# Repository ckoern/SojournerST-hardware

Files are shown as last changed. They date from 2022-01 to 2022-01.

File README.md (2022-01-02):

# SojournerST-hardware
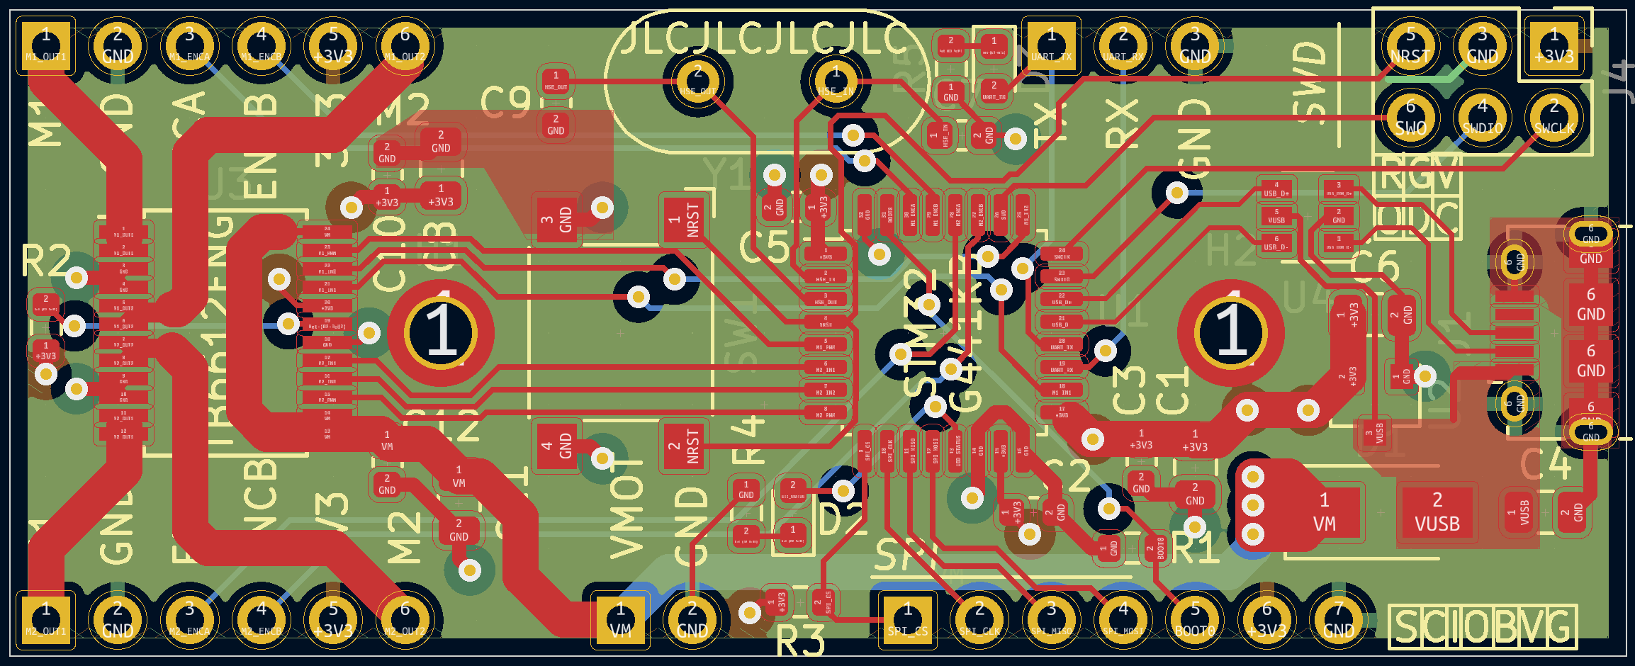
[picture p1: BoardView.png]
Board Top View

KiCad project for the SojournerST two-channel closed-loop Motor Driver Board.
The firmware project can be found [here](https://github.com/ckoern/SojournerST).

The board is based on the TB6612 motor driver IC controlled via an STM32G441 (F4 should work as well) microcontroller and is designed to fit into a breadboard but also provides mounting holes to integrate it into a custom platform.

The controller uses quadrature encoder input to provide closed-loop PWM control to the driver IC. Power can either be supplied via USB to supply both logic and driver voltage or via a 3V3 logic and a motor voltage input (max. 15V).

Commanding can be done via UART or SPI.

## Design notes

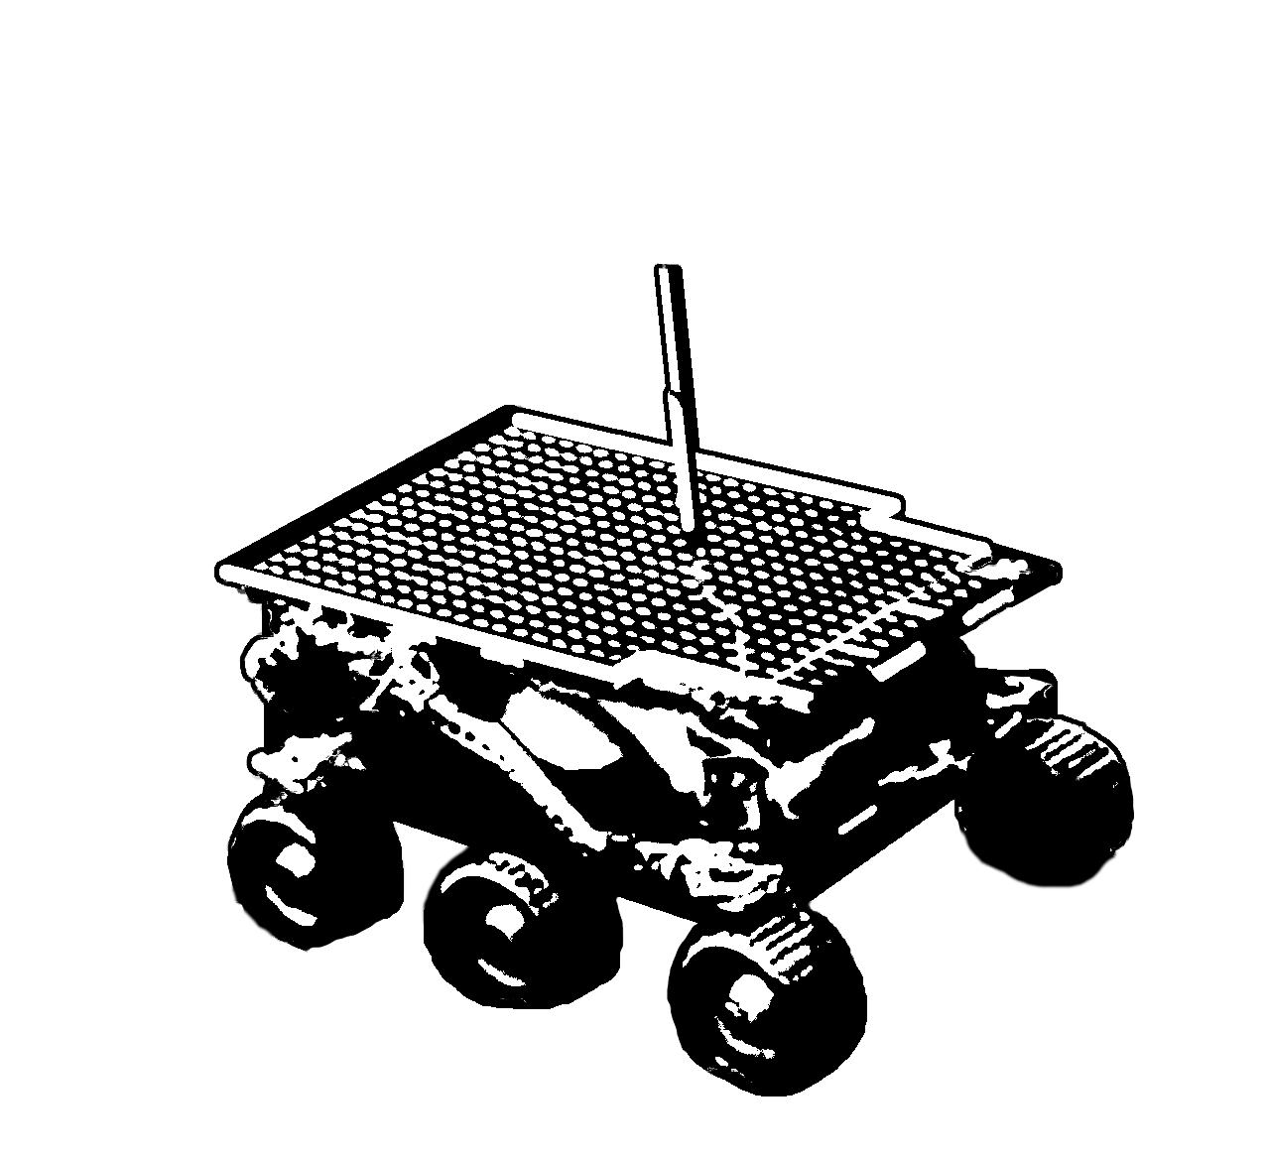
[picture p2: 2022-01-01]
SojournerST/Sojourner_on_Mars_PIA01122_2.png

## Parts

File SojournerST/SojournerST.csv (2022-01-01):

Source: | D:\Benutzer\Christian\Documents\KiCad\SojournerST\SojournerST\SojournerST.sch
Date: | 22.05.2021 18:16:42
Tool: | Eeschema (5.1.9)-1
Generator: | D:\Program Files\KiCad\bin\scripting\plugins/bom_csv_grouped_by_value.py
Component Count: | 35
Individual Components:
Item | Qty | Reference(s) | Value | LibPart | Footprint | Datasheet
 |  | C1 | 4.7u | Device:C_Small | Capacitor_SMD:C_0805_2012Metric | ~
 |  | C2 | 100n | Device:C_Small | Capacitor_SMD:C_0603_1608Metric | ~
 |  | C3 | 100n | Device:C_Small | Capacitor_SMD:C_0603_1608Metric | ~
 |  | C4 | 1u | Device:C_Small | Capacitor_SMD:C_0805_2012Metric | ~
 |  | C5 | 100n | Device:C_Small | Capacitor_SMD:C_0603_1608Metric | ~
 |  | C6 | 1u | Device:C_Small | Capacitor_SMD:C_0805_2012Metric | ~
 |  | C7 | 10p | Device:C_Small | Capacitor_SMD:C_0603_1608Metric | ~
 |  | C8 | 10u | Device:C_Small | Capacitor_SMD:C_0805_2012Metric | ~
 |  | C9 | 10p | Device:C_Small | Capacitor_SMD:C_0603_1608Metric | ~
 |  | C10 | 100n | Device:C_Small | Capacitor_SMD:C_0603_1608Metric | ~
 |  | C11 | 10u | Device:C_Small | Capacitor_SMD:C_0805_2012Metric | ~
 |  | C12 | 100n | Device:C_Small | Capacitor_SMD:C_0603_1608Metric | ~
 |  | D1 | D | Device:D | Diode_SMD:D_SMA | ~
 |  | D2 | LED | Device:LED | LED_SMD:LED_0603_1608Metric | ~
 |  | D3 | LED | Device:LED | LED_SMD:LED_0603_1608Metric | ~
 |  | H1 | MountingHole | Mechanical:MountingHole | MountingHole:MountingHole_2.2mm_M2_DIN965_Pad_TopOnly | ~
 |  | H2 | MountingHole | Mechanical:MountingHole | MountingHole:MountingHole_2.2mm_M2_DIN965_Pad_TopOnly | ~
 |  | J1 | USB_B_Micro | Connector:USB_B_Micro | Connector_USB:USB_Micro-B_Amphenol_10118194_Horizontal | ~
 |  | J2 | Conn_01x07 | Connector_Generic:Conn_01x07 | Connector_PinHeader_2.54mm:PinHeader_1x07_P2.54mm_Vertical | ~
 |  | J3 | Conn_01x03 | Connector_Generic:Conn_01x03 | Connector_PinHeader_2.54mm:PinHeader_1x03_P2.54mm_Vertical | ~
 |  | J4 | Conn_01x06 | Connector_Generic:Conn_01x06 | Connector_PinHeader_2.54mm:PinHeader_2x03_P2.54mm_Vertical | ~
 |  | J5 | Conn_01x06 | Connector_Generic:Conn_01x06 | Connector_PinHeader_2.54mm:PinHeader_1x06_P2.54mm_Vertical | ~
 |  | J6 | Conn_01x06 | Connector_Generic:Conn_01x06 | Connector_PinHeader_2.54mm:PinHeader_1x06_P2.54mm_Vertical | ~
 |  | J7 | Conn_01x02 | Connector_Generic:Conn_01x02 | Connector_PinHeader_2.54mm:PinHeader_1x02_P2.54mm_Vertical | ~
 |  | R1 | 10k | Device:R_Small | Resistor_SMD:R_0603_1608Metric | ~
 |  | R2 | 10k | Device:R_Small | Resistor_SMD:R_0603_1608Metric | ~
 |  | R3 | 10k | Device:R_Small | Resistor_SMD:R_0603_1608Metric | ~
 |  | R4 | 330 | Device:R_Small | Resistor_SMD:R_0603_1608Metric | ~
 |  | R5 | 330 | Device:R_Small | Resistor_SMD:R_0603_1608Metric | ~
 |  | SW1 | SW_MEC_5E | Switch:SW_MEC_5E | Button_Switch_SMD:SW_SPST_Omron_B3FS-100xP | http://www.apem.com/int/index.php?controller=attachment&id_attachment=1371
 |  | U1 | STM32G441KBTx | MCU_ST_STM32G4:STM32G441KBTx | Package_QFP:LQFP-32_7x7mm_P0.8mm | http://www.st.com/st-web-ui/static/active/en/resource/technical/document/datasheet/DM00097745.pdf
 |  | U2 | LM1117-3.3 | Regulator_Linear:LM1117-3.3 | Package_TO_SOT_SMD:SOT-23 | http://www.ti.com/lit/ds/symlink/lm1117.pdf
 |  | U3 | TB6612FNG | Driver_Motor:TB6612FNG | Package_SO:SSOP-24_5.3x8.2mm_P0.65mm | https://toshiba.semicon-storage.com/us/product/linear/motordriver/detail.TB6612FNG.html
 |  | U4 | USBLC6-2SC6 | Power_Protection:USBLC6-2SC6 | Package_TO_SOT_SMD:SOT-23-6 | https://www.st.com/resource/en/datasheet/usblc6-2.pdf
 |  | Y1 | Crystal | Device:Crystal | Crystal:Crystal_HC49-4H_Vertical | ~
Collated Components:
Item | Qty | Reference(s) | Value | LibPart | Footprint | Datasheet
1 | 1 | C1 | 4.7u | Device:C_Small | Capacitor_SMD:C_0805_2012Metric | ~
2 | 5 | C2, C3, C5, C10, C12 | 100n | Device:C_Small | Capacitor_SMD:C_0603_1608Metric | ~
3 | 2 | C4, C6 | 1u | Device:C_Small | Capacitor_SMD:C_0805_2012Metric | ~
4 | 2 | C7, C9 | 10p | Device:C_Small | Capacitor_SMD:C_0603_1608Metric | ~
5 | 2 | C8, C11 | 10u | Device:C_Small | Capacitor_SMD:C_0805_2012Metric | ~
6 | 1 | D1 | D | Device:D | Diode_SMD:D_SMA | ~
7 | 2 | D2, D3 | LED | Device:LED | LED_SMD:LED_0603_1608Metric | ~
8 | 2 | H1, H2 | MountingHole | Mechanical:MountingHole | MountingHole:MountingHole_2.2mm_M2_DIN965_Pad_TopOnly | ~
9 | 1 | J1 | USB_B_Micro | Connector:USB_B_Micro | Connector_USB:USB_Micro-B_Amphenol_10118194_Horizontal | ~
10 | 1 | J2 | Conn_01x07 | Connector_Generic:Conn_01x07 | Connector_PinHeader_2.54mm:PinHeader_1x07_P2.54mm_Vertical | ~
11 | 1 | J3 | Conn_01x03 | Connector_Generic:Conn_01x03 | Connector_PinHeader_2.54mm:PinHeader_1x03_P2.54mm_Vertical | ~
12 | 1 | J4 | Conn_01x06 | Connector_Generic:Conn_01x06 | Connector_PinHeader_2.54mm:PinHeader_2x03_P2.54mm_Vertical | ~
13 | 2 | J5, J6 | Conn_01x06 | Connector_Generic:Conn_01x06 | Connector_PinHeader_2.54mm:PinHeader_1x06_P2.54mm_Vertical | ~
14 | 1 | J7 | Conn_01x02 | Connector_Generic:Conn_01x02 | Connector_PinHeader_2.54mm:PinHeader_1x02_P2.54mm_Vertical | ~
15 | 3 | R1, R2, R3 | 10k | Device:R_Small | Resistor_SMD:R_0603_1608Metric | ~
16 | 2 | R4, R5 | 330 | Device:R_Small | Resistor_SMD:R_0603_1608Metric | ~
17 | 1 | SW1 | SW_MEC_5E | Switch:SW_MEC_5E | Button_Switch_SMD:SW_SPST_Omron_B3FS-100xP | http://www.apem.com/int/index.php?controller=attachment&id_attachment=1371
18 | 1 | U1 | STM32G441KBTx | MCU_ST_STM32G4:STM32G441KBTx | Package_QFP:LQFP-32_7x7mm_P0.8mm | http://www.st.com/st-web-ui/static/active/en/resource/technical/document/datasheet/DM00097745.pdf
19 | 1 | U2 | LM1117-3.3 | Regulator_Linear:LM1117-3.3 | Package_TO_SOT_SMD:SOT-23 | http://www.ti.com/lit/ds/symlink/lm1117.pdf
20 | 1 | U3 | TB6612FNG | Driver_Motor:TB6612FNG | Package_SO:SSOP-24_5.3x8.2mm_P0.65mm | https://toshiba.semicon-storage.com/us/product/linear/motordriver/detail.TB6612FNG.html
21 | 1 | U4 | USBLC6-2SC6 | Power_Protection:USBLC6-2SC6 | Package_TO_SOT_SMD:SOT-23-6 | https://www.st.com/resource/en/datasheet/usblc6-2.pdf
22 | 1 | Y1 | Crystal | Device:Crystal | Crystal:Crystal_HC49-4H_Vertical | ~

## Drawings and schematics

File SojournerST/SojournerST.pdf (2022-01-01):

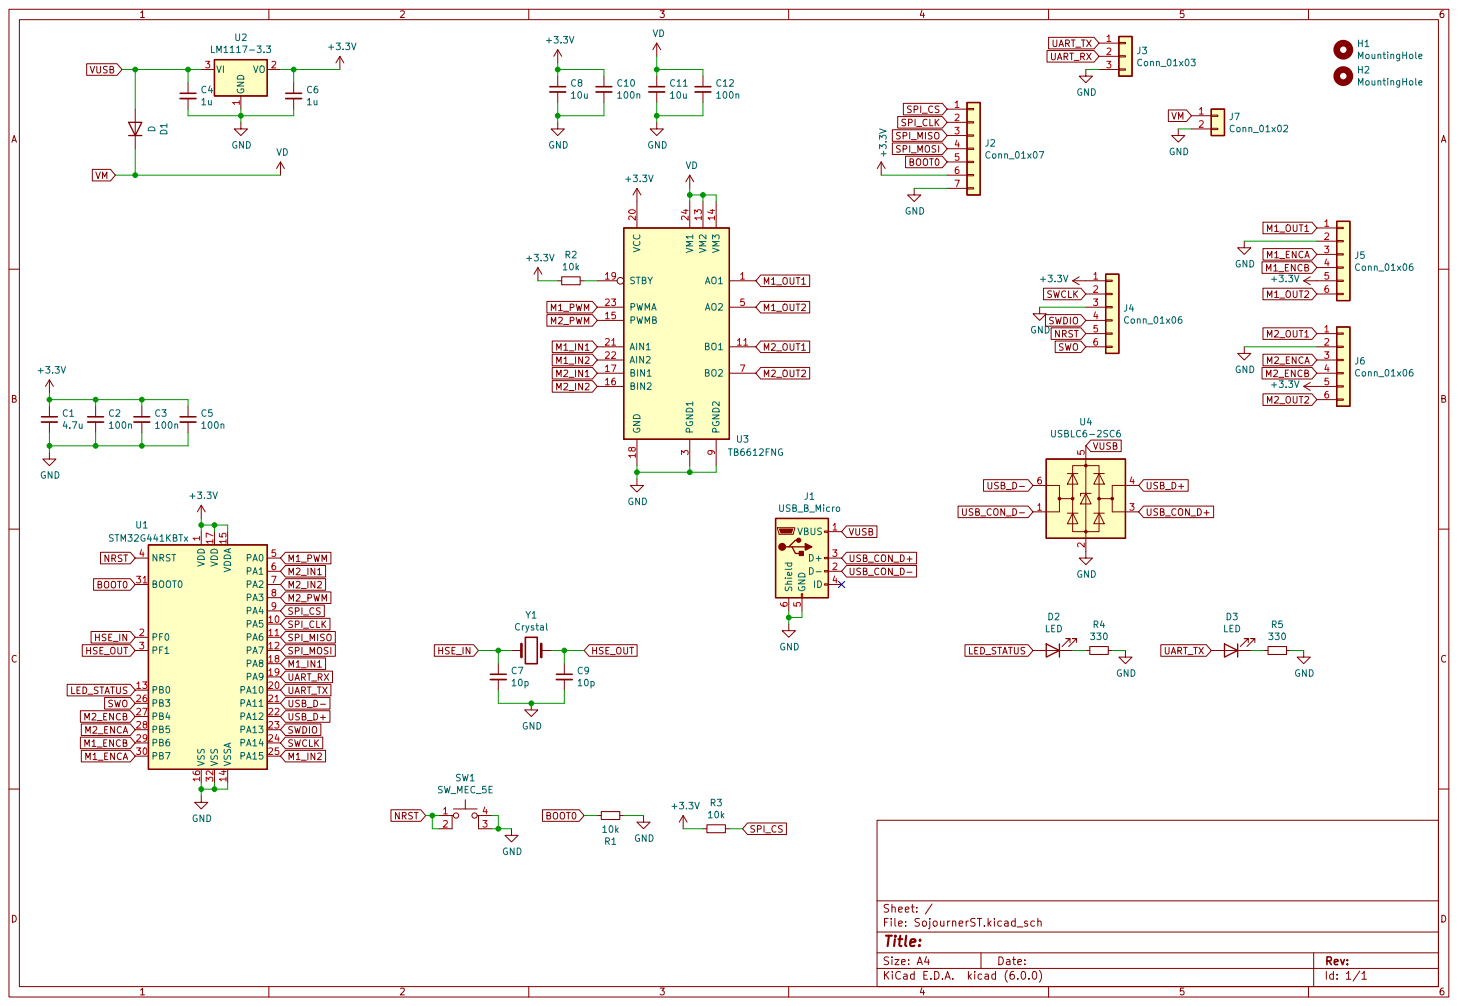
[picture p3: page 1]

1 PA5 10 PA6 11 PA7 12 PB0 13 VSSA 14 VDDA 15 VSS 16 VDD 17 PA8 18 PA9 19 PF0 2 PA10 20 PA11 21 PA12 22 PA13 23 PA14 24 PA15 25 PB3 26 PB4 27 PB5 28 PB6 29 PF1 3 PB7 30 BOOT0 31 VSS 32 NRST 4 PA0 5 PA1 6 PA2 7 PA3 8 PA4 9 U1 STM32G441KBTx C2

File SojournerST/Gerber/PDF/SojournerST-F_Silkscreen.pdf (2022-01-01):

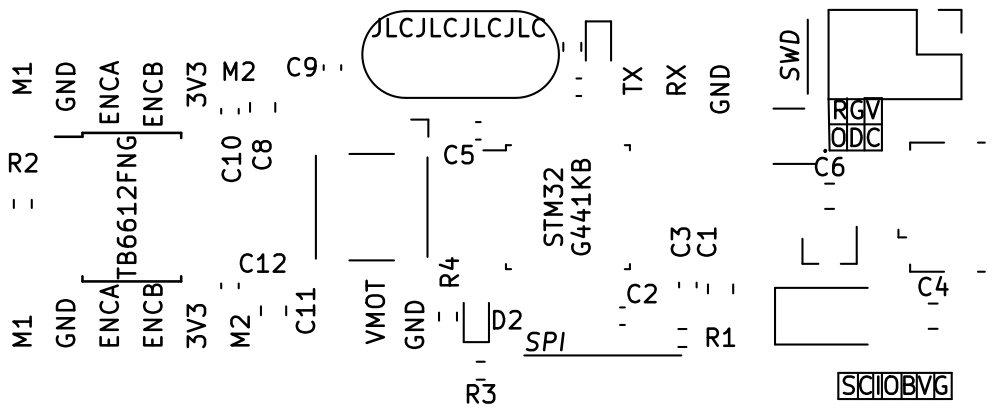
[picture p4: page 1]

M2 GND ENCB 3V3 ENCA GNDM1M2 . GND

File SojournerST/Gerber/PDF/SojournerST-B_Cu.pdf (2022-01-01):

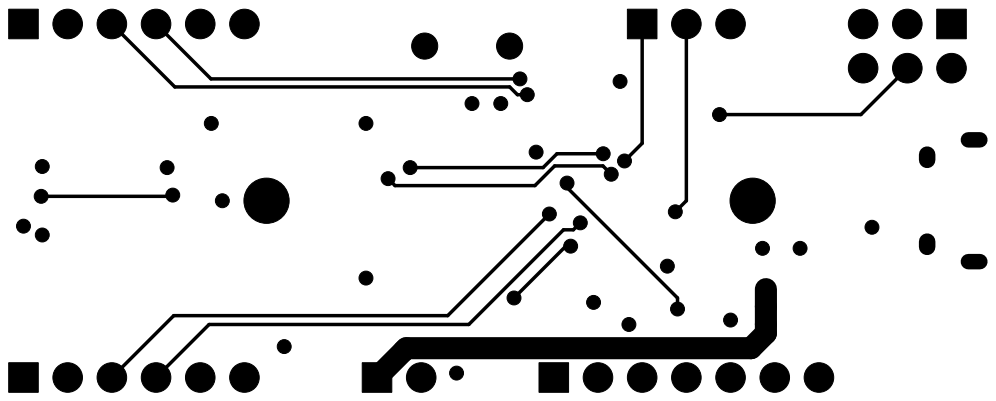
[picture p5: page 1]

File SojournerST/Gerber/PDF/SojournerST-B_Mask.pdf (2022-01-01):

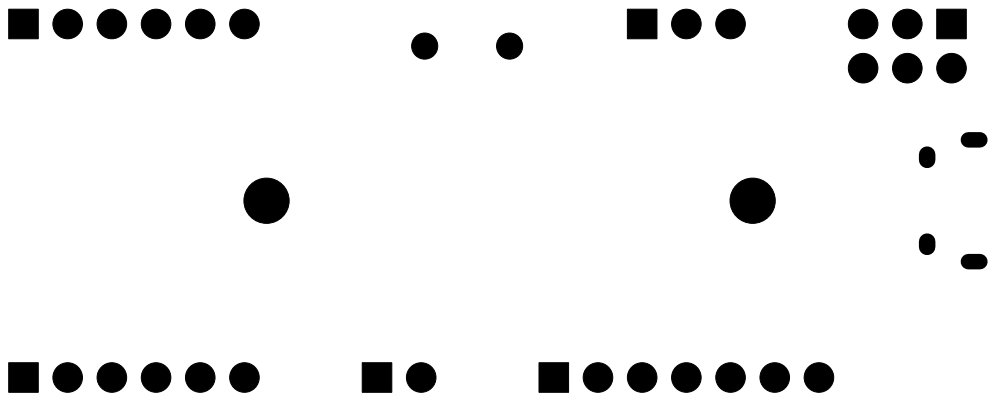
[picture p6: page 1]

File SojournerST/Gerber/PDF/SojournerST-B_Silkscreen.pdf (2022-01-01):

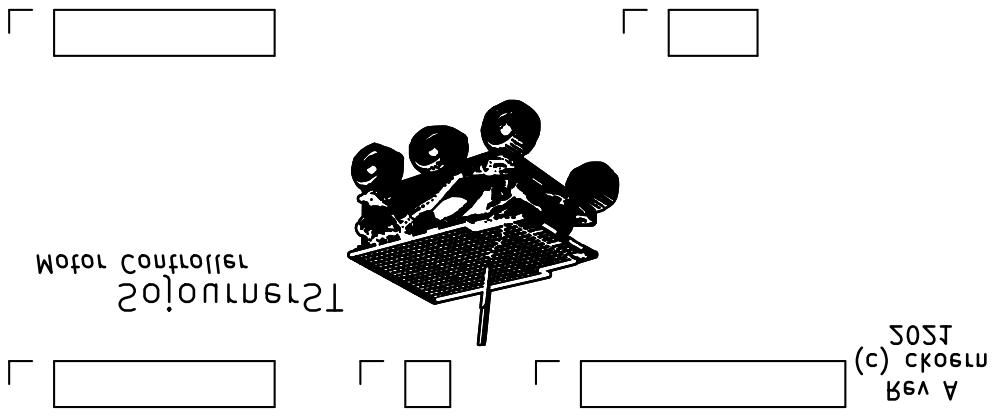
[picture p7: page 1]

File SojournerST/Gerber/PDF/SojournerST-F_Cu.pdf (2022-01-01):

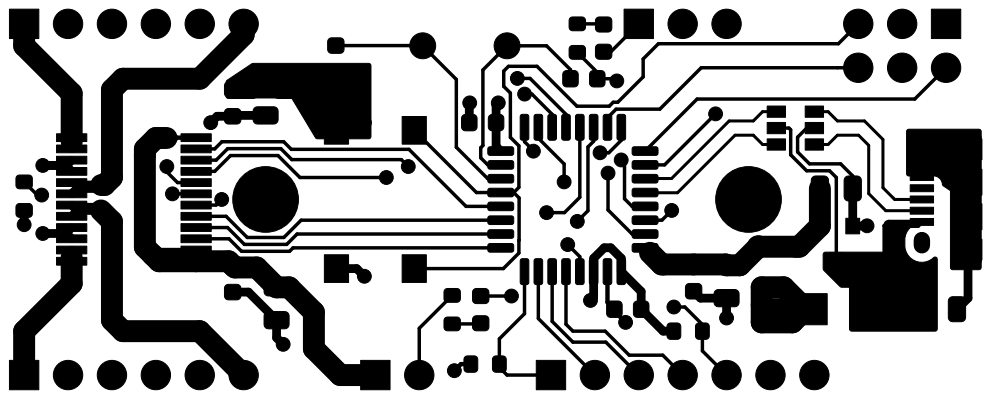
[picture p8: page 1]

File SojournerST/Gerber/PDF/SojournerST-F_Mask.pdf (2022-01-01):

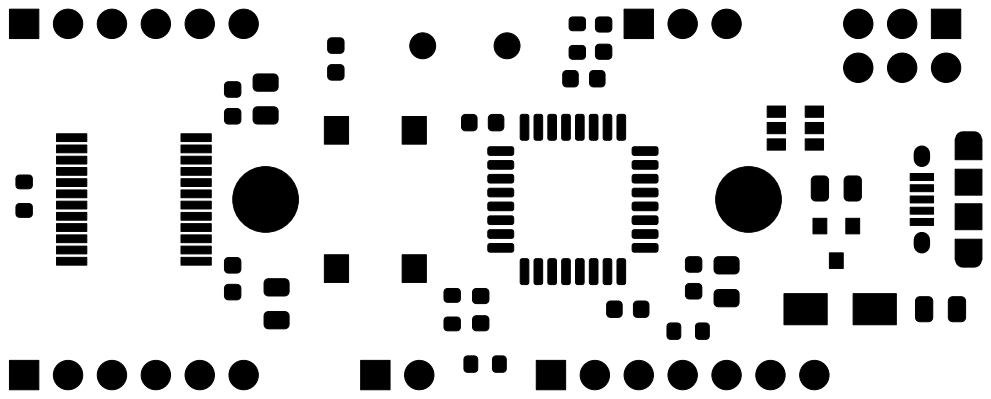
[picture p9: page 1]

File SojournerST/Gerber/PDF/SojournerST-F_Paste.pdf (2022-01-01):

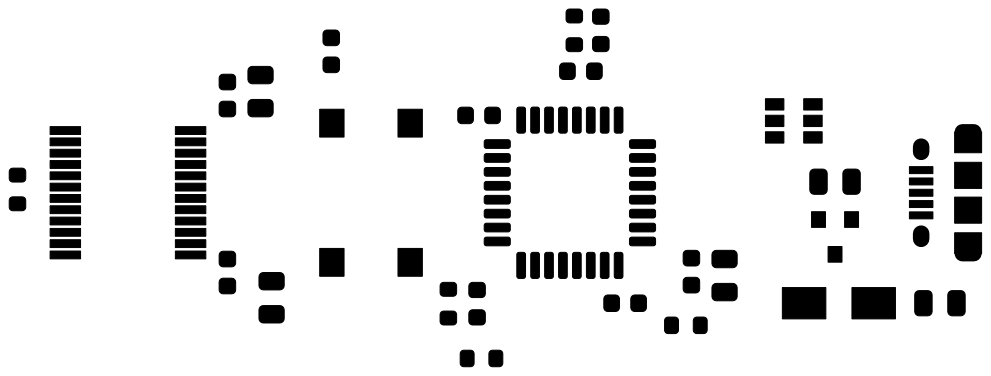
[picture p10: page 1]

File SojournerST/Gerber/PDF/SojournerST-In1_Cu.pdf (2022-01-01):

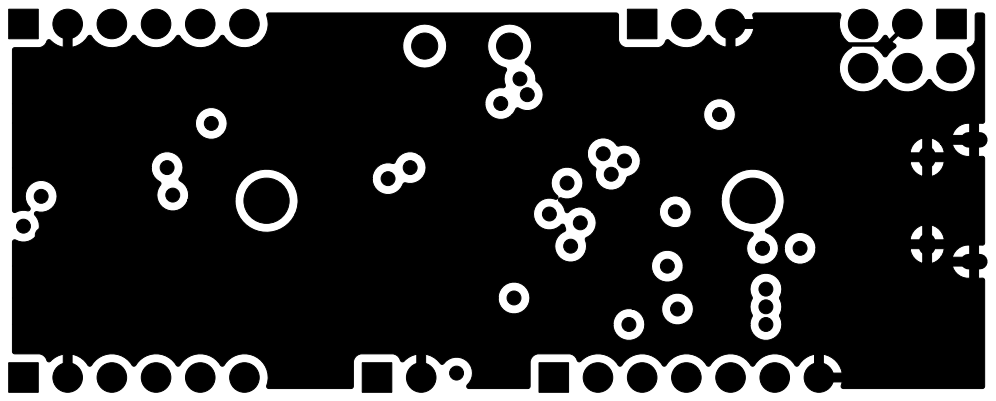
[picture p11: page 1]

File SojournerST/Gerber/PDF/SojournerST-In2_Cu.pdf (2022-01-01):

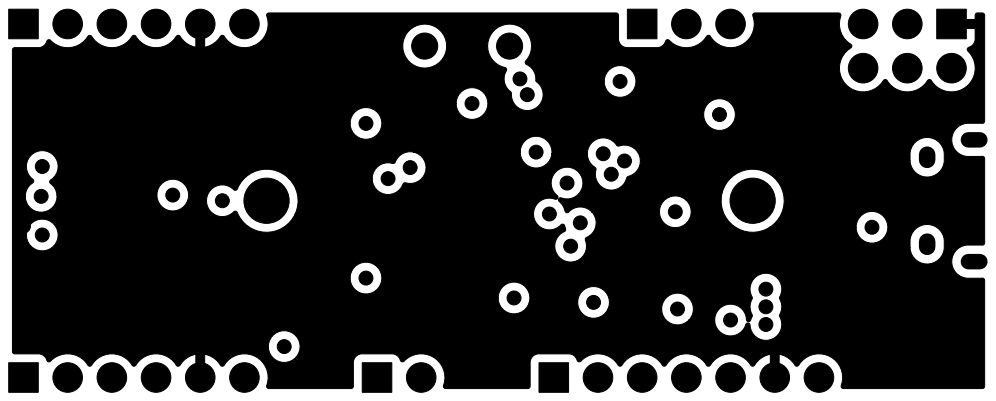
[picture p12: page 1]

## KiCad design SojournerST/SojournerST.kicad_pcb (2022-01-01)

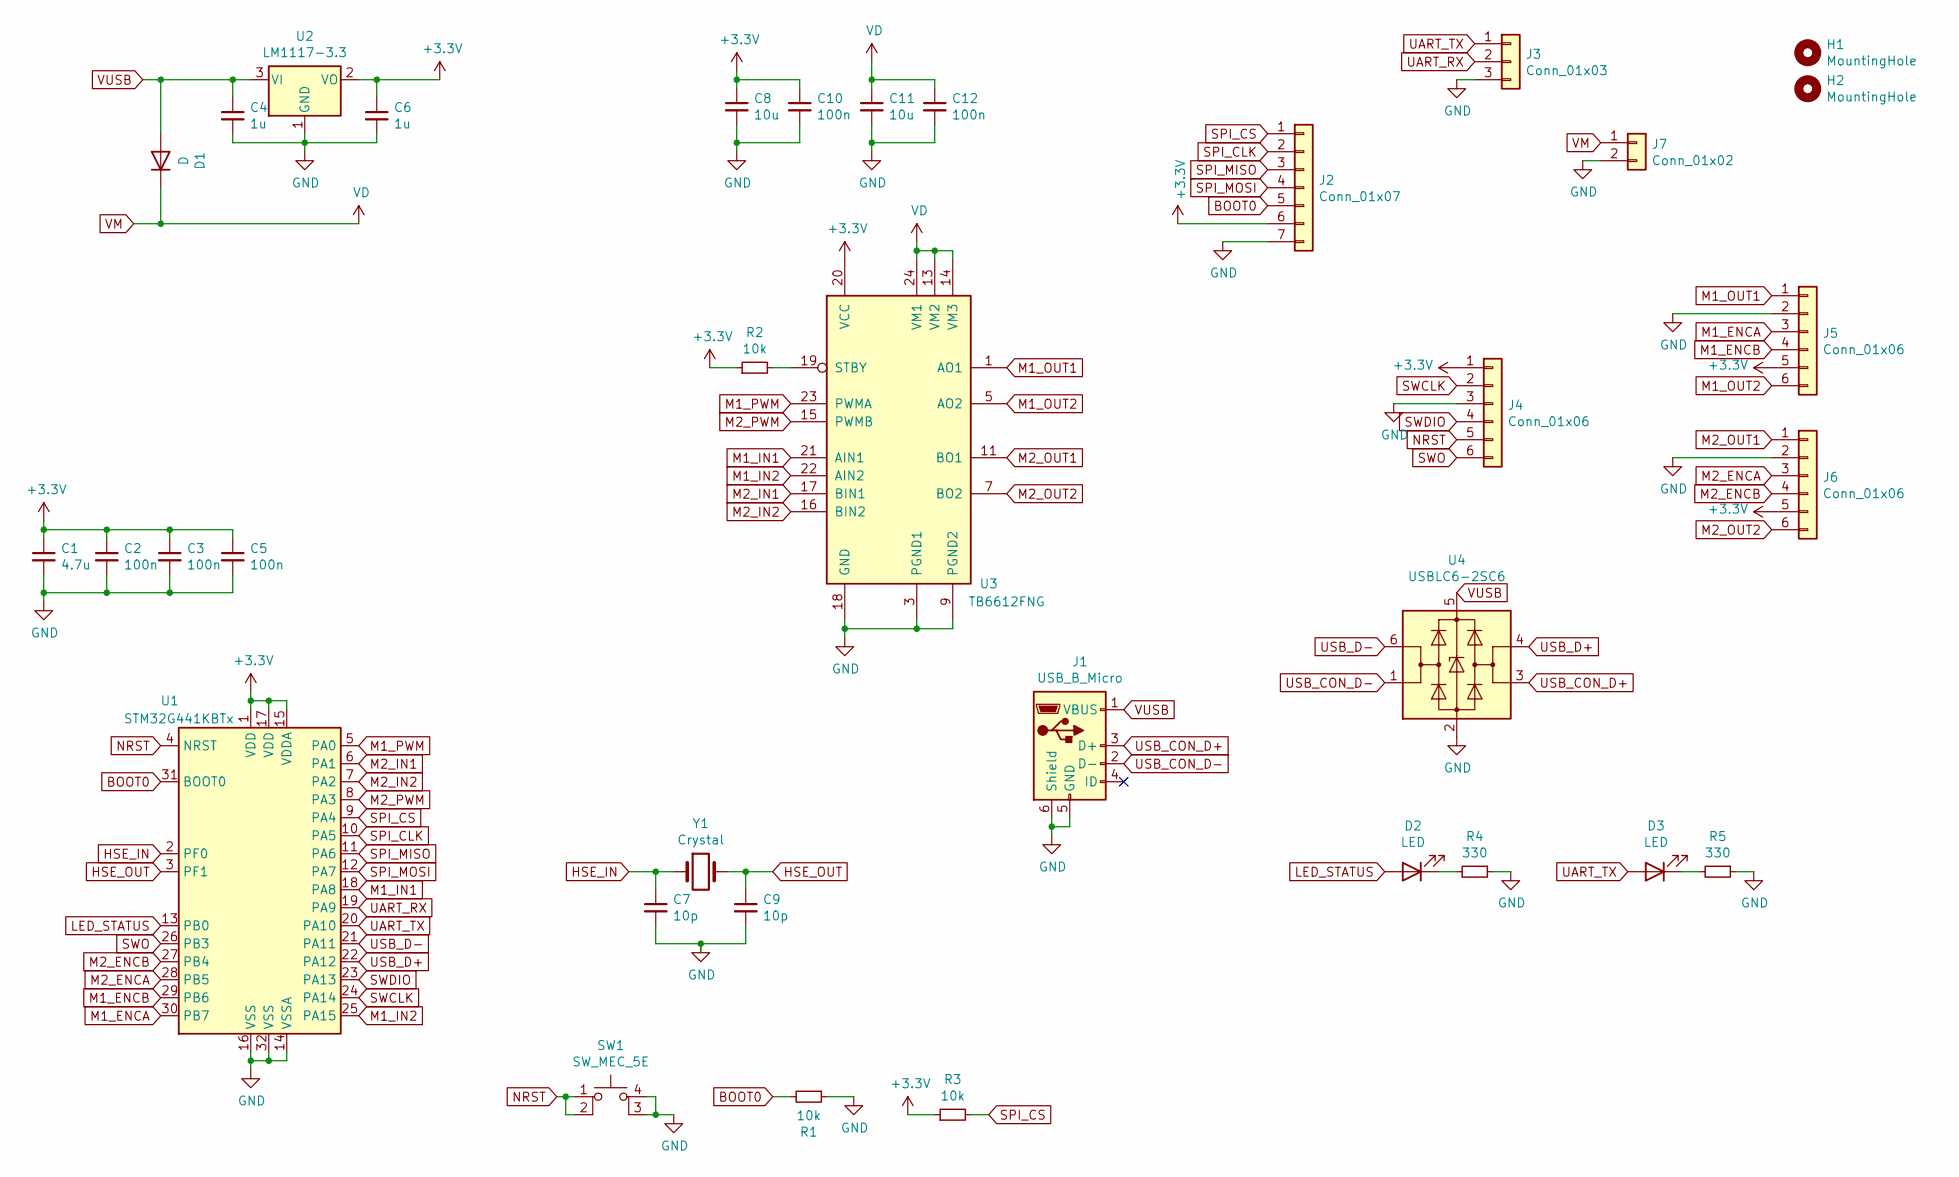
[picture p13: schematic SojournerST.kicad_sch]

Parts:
C1: 4.7u; C_0805_2012Metric
C2, C3, C5, C10, C12: 100n; C_0603_1608Metric
C4, C6: 1u; C_0805_2012Metric
C7, C9: 10p; C_0603_1608Metric
C8, C11: 10u; C_0805_2012Metric
D1: D; D_SMA
D2, D3: LED; LED_0603_1608Metric
H1, H2: MountingHole; MountingHole_2.2mm_M2_DIN965_Pad_TopOnly
J1: USB_B_Micro; USB_Micro-B_Amphenol_10118194_Horizontal
J2: Conn_01x07; PinHeader_1x07_P2.54mm_Vertical
J3: Conn_01x03; PinHeader_1x03_P2.54mm_Vertical
J4: Conn_01x06; PinHeader_2x03_P2.54mm_Vertical
J5, J6: Conn_01x06; PinHeader_1x06_P2.54mm_Vertical
J7: Conn_01x02; PinHeader_1x02_P2.54mm_Vertical
R1, R2, R3: 10k; R_0603_1608Metric
R4, R5: 330; R_0603_1608Metric
SW1: SW_MEC_5E; SW_SPST_Omron_B3FS-100xP
U1: STM32G441KBTx; LQFP-32_7x7mm_P0.8mm
U2: LM1117-3.3; SOT-23
U3: TB6612FNG; SSOP-24_5.3x8.2mm_P0.65mm
U4: USBLC6-2SC6; SOT-23-6
Y1: Crystal; Crystal_HC49-4H_Vertical

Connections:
+3V3: C1.1, C2.1, C3.1, C5.1, C6.1, C8.1, C10.1, J2.6, J4.1, J5.5, J6.5, R2.1, R3.1, U1.1 (VDD), U1.15 (VDDA), U1.17 (VDD), U2.2 (VO), U3.20 (VCC)
BOOT0: J2.5, R1.2, U1.31 (BOOT0)
GND: C1.2, C2.2, C3.2, C4.2, C5.2, C6.2, C7.2, C8.2, C9.2, C10.2, C11.2, C12.2, J1.5 (GND), J1.6 (Shield), J2.7, J3.3, J4.3, J5.2, J6.2, J7.2, R1.1, R4.1, R5.1, SW1.3 (K), SW1.4 (A), U1.14 (VSSA), U1.16 (VSS), U1.32 (VSS), U2.1 (GND), U3.3 (PGND1), U3.4 (PGND1), U3.9 (PGND2), U3.10 (PGND2), U3.18 (GND), U4.2 (GND)
HSE_IN: C7.1, U1.2 (PF0), Y1.1
HSE_OUT: C9.1, U1.3 (PF1), Y1.2
LED_STATUS: D2.2 (A), U1.13 (PB0)
M1_ENCA: J5.3, U1.30 (PB7)
M1_ENCB: J5.4, U1.29 (PB6)
M1_IN1: U1.18 (PA8), U3.21 (AIN1)
M1_IN2: U1.25 (PA15), U3.22 (AIN2)
M1_OUT1: J5.1, U3.1 (AO1), U3.2 (AO1)
M1_OUT2: J5.6, U3.5 (AO2), U3.6 (AO2)
M1_PWM: U1.5 (PA0), U3.23 (PWMA)
M2_ENCA: J6.3, U1.28 (PB5)
M2_ENCB: J6.4, U1.27 (PB4)
M2_IN1: U1.6 (PA1), U3.17 (BIN1)
M2_IN2: U1.7 (PA2), U3.16 (BIN2)
M2_OUT1: J6.1, U3.11 (BO1), U3.12 (BO1)
M2_OUT2: J6.6, U3.7 (BO2), U3.8 (BO2)
M2_PWM: U1.8 (PA3), U3.15 (PWMB)
NRST: J4.5, SW1.1, SW1.2, U1.4 (NRST)
unnamed: D2.1 (K), R4.2
unnamed: D3.1 (K), R5.2
unnamed: R2.2, U3.19 (STBY)
SPI_CLK: J2.2, U1.10 (PA5)
SPI_CS: J2.1, R3.2, U1.9 (PA4)
SPI_MISO: J2.3, U1.11 (PA6)
SPI_MOSI: J2.4, U1.12 (PA7)
SWCLK: J4.2, U1.24 (PA14)
SWDIO: J4.4, U1.23 (PA13)
SWO: J4.6, U1.26 (PB3)
UART_RX: J3.2, U1.19 (PA9)
UART_TX: D3.2 (A), J3.1, U1.20 (PA10)
USB_CON_D+: J1.3 (D+), U4.3 (I/O2)
USB_CON_D-: J1.2 (D-), U4.1 (I/O1)
USB_D+: U1.22 (PA12), U4.4 (I/O2)
USB_D-: U1.21 (PA11), U4.6 (I/O1)
VM: C11.1, C12.1, D1.1 (K), J7.1, U3.13 (VM2), U3.14 (VM3), U3.24 (VM1)
VUSB: C4.1, D1.2 (A), J1.1 (VBUS), U2.3 (VI), U4.5 (VBUS)

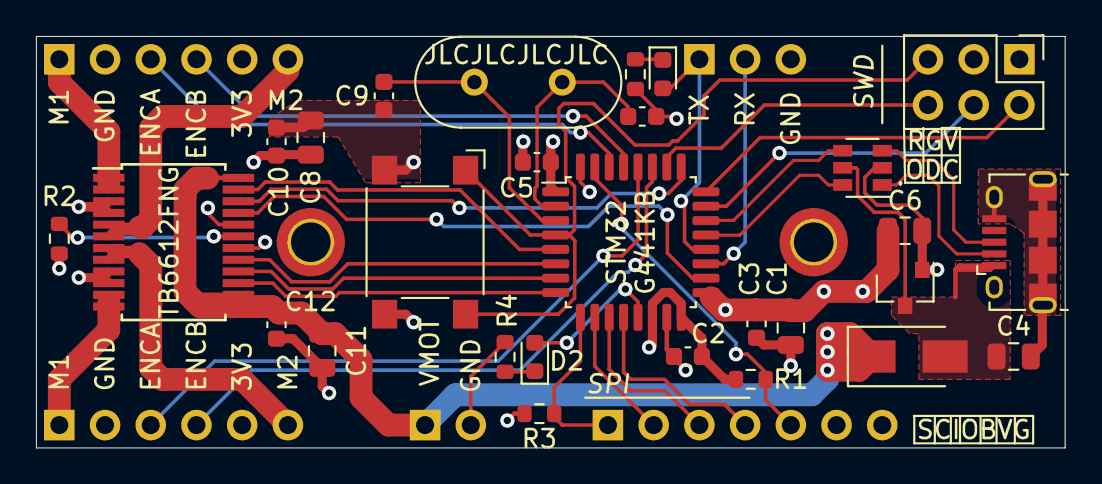
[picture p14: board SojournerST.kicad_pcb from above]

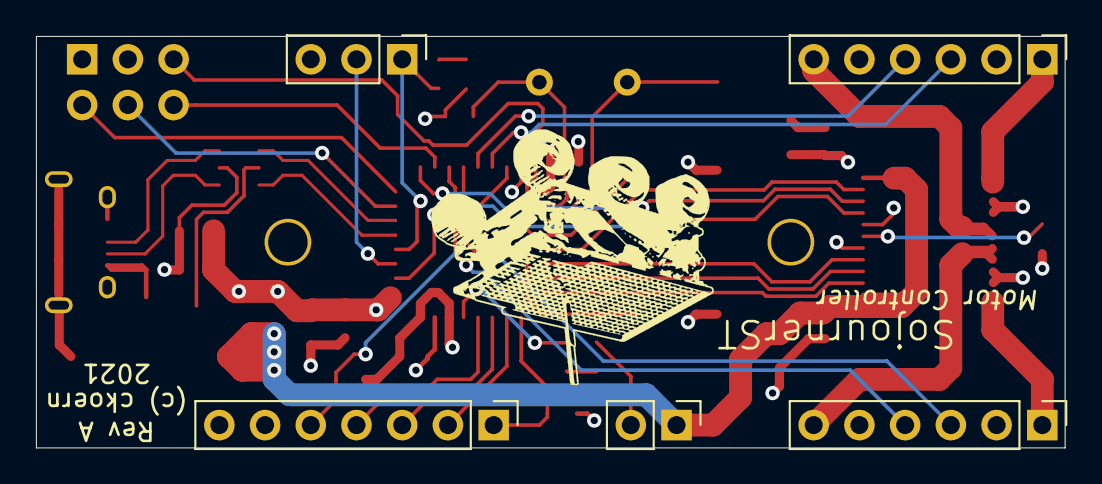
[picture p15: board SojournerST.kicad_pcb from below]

Board: 4 copper layers, 57.1 x 22.9 mm, 35 parts (5 on the bottom side), 39 nets.

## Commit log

2022-01-01 Inital commit containing the Rev A board files
    [SojournerST-B_Cu.gbr, SojournerST-B_Mask.gbr, SojournerST-B_Paste.gbr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]
2022-01-01 Moved project into a subdirectory
    [SojournerST-B_Cu.gbr, SojournerST-B_Mask.gbr, SojournerST-B_Paste.gbr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]
